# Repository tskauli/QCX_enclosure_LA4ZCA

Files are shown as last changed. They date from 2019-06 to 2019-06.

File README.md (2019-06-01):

# QCX_enclosure_LA4ZCA
A compact enclosure with integrated paddles for the QCX amateur radio transceiver kit

This note describes a design for a 3D printed enclosure for the QCX transceiver kit from QRP labs. The goal for the design has been to make a small and self-contained unit, to make it easy to bring the transceiver along for portable operation. Therefore, many features are built in:
•	paddles which can be flipped to a parking position for storage
•	speaker, in addition to an earphone connector
•	LiPo 4s battery, giving a transmit power of 5W
•	GPS for WSPR operation, enabled or disabled by the power switch

Construction is described in some detail in the document "Compact 3D printed QCX enclosure - construction notes"

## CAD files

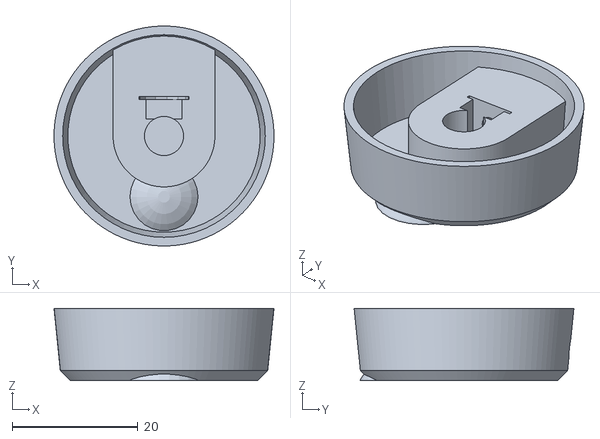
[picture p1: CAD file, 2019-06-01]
QCXtuning.stl
35.0 x 35.0 x 11.5

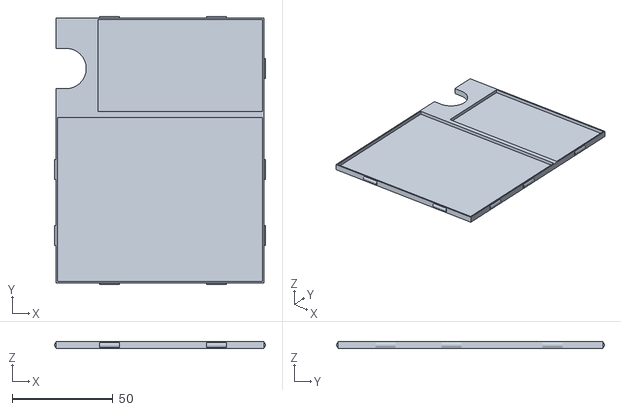
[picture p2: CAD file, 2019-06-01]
QCXcabinetLA4ZCAv30Lid.stl
104.5 x 132.7 x 3.50

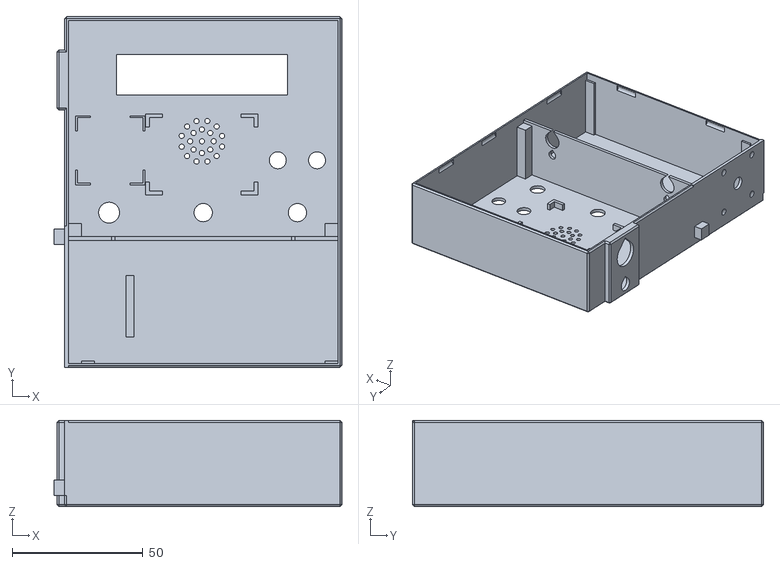
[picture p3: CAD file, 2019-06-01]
QCXcabinetLA4ZCAv30.stl
110.0 x 134.2 x 33.0

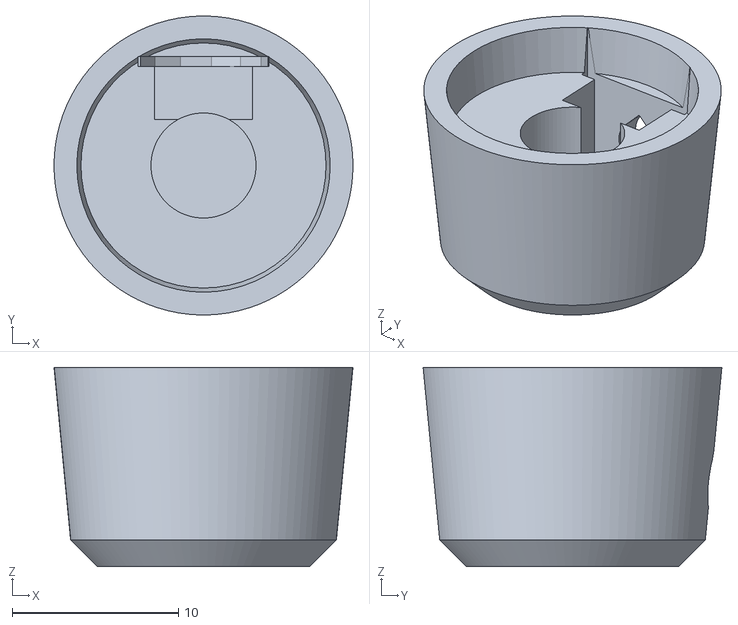
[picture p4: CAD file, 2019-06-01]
QCXvolume.stl
18.0 x 18.0 x 12.0

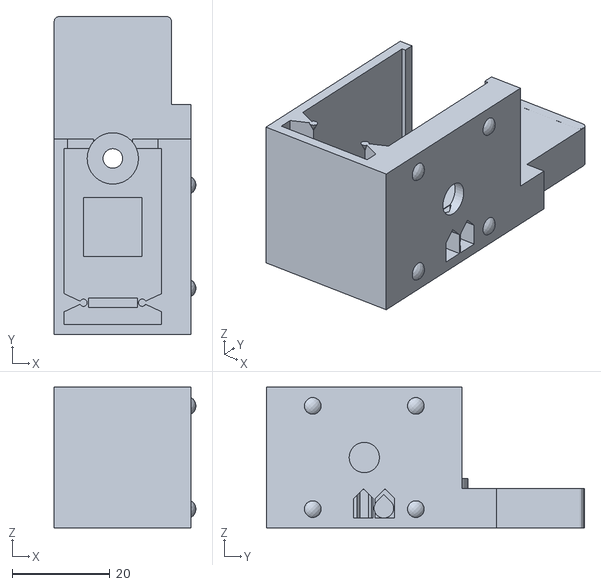
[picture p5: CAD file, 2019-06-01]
MorsePaddlesV2Base.stl
29.0 x 65.0 x 28.8

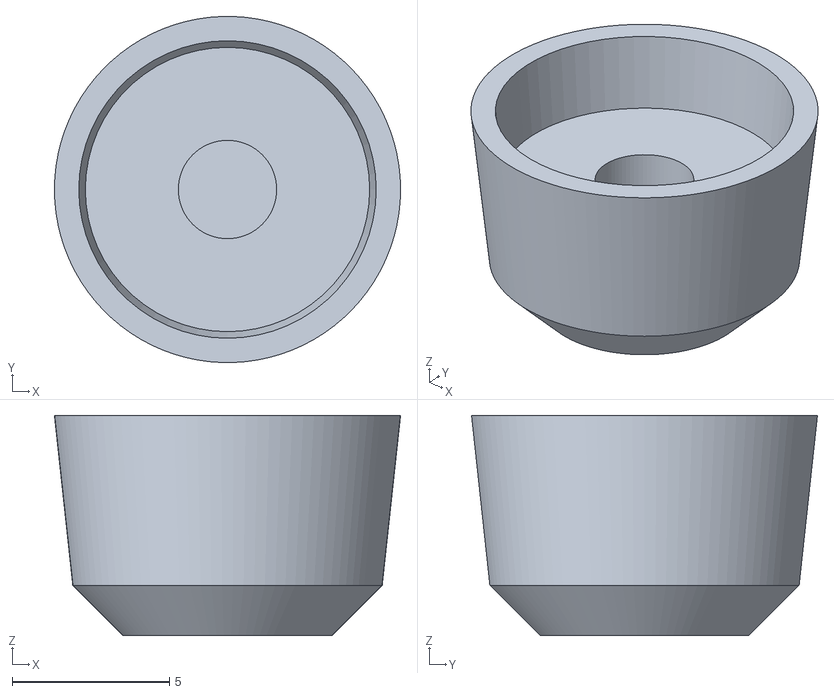
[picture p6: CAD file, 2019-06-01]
QCXpushbutton.stl
11.0 x 11.0 x 7.00

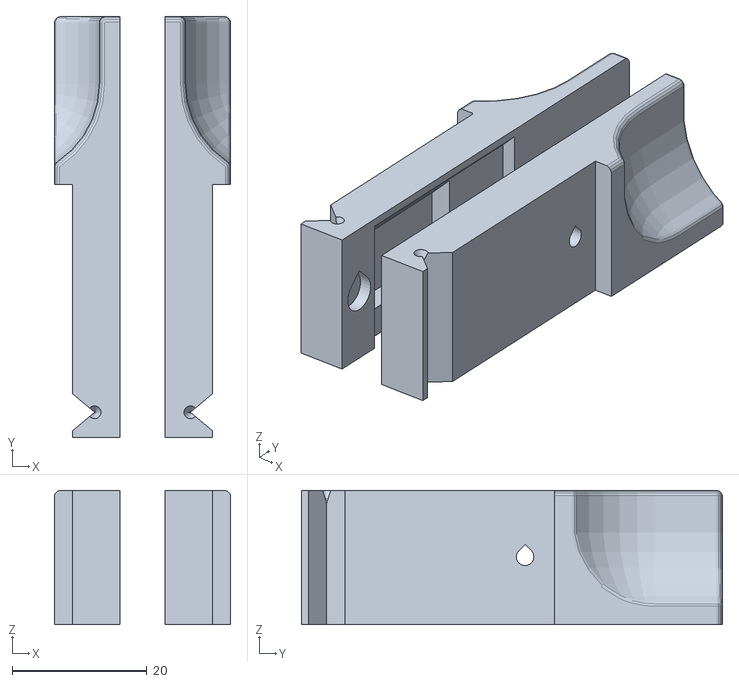
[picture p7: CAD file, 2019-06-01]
MorsePaddlesV2Arms.stl
26.2 x 62.6 x 20.0

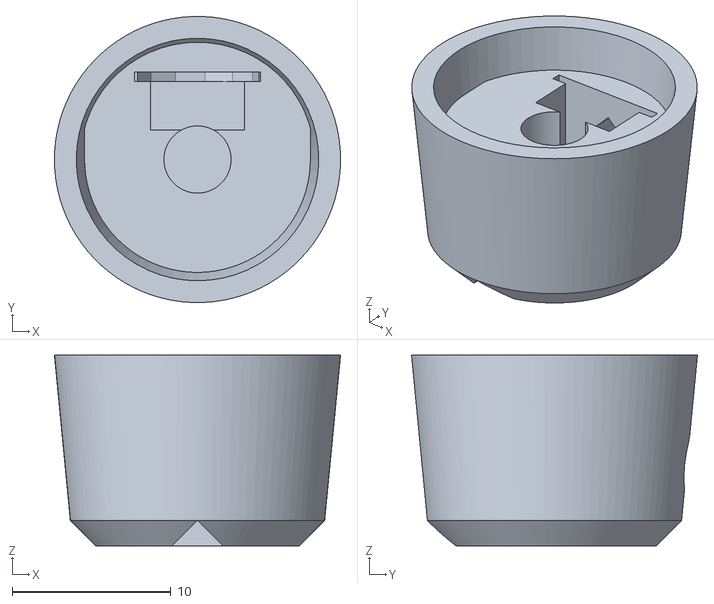
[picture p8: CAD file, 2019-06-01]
QCXpower.stl
18.0 x 18.0 x 12.0

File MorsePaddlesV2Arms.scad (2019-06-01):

/*

           >>> COMPACT 3D-PRINTED PADDLES <<<


    Torbjørn Skauli, LA4ZCA (tskauli@gmail.com)

                  v2.0, December 2018


Iambic paddles designed for 3D-printing. The design is simple, but provides precise movement with adjustable force and travel. Design features include a printed rocker hinge, force adjustment by a sliding spring, travel adjustment using a modified screw, ergonomic grip and general simplicity and precision.

Changes in v2.0: The paddles have been made narrower, and the base is thinner. There is an option to remove the bottom mounting holes. The base extends under the paddles to protect them from being pushed upwards. The cable exit is on the side, to fit mounting on the QCX transceiver.

TODO:
-Arms 1-2 mm higher, spring channel longer towards contacts?

Materials:
- 3 printed parts
- 2 screws M3x5mm, cylinder head, with washers for adjustment if needed
- 1 screw M4x25mm, cylinder head, with washer and nut
- Compression spring, 6-8 mm in diameter
- Compression spring, 4-5 mm in diameter
- Cable with plug as required, up to 3.5 mm diameter
Note: Dimensions of screws, springs and cable can be changed in the code.

Assembly:

- First, prepare the 3D-printed parts by removing support material in the arm spring well and in the ends of the cable holes. Also remove any protuding edges and bumps by gently filing the surfaces.

- Place the large spring so that it is held between the paddles approximately in the middle of the spring well. Also place the small spring in the holes at the hinge. Temporarily slide the two paddles in place. Check the spring force on the paddles and adjust as desired by either moving the spring along the well or by bending the spring to change its length. Make sure that the small spring keeps the arms in place at the hinges during use.

- Remove 6-8 cm of the outer isolation (if present) of the cable and 1 cm of the inner isolation of each wire. Insert the cable from the back through the diagonal hole, and temporarily pull it out from the side "window". Insert the cable back into the other hole and press the cable bend into the window so that the outer isolation ends in the interior wiring well. This forms a strain relief.

- Prepare a 25 mm (XXcheck) M4 screw with cylindrical head by grinding the outer 10 mm to flatten two opposing sides. Preferably align the flattened screw end with the slot in the screw head.

- Enter two M3 screws with cylindrical heads into the paddle arms, with the heads facing inwards. Clamp the dot and dash wire ends under these screw heads.

- Enter the M4 screw from the bottom and clamp the ground wire underneath the washer. Tighten the screw firmly, while allowing a small amount of adjustment of the screw angle to set the travel distance.

- Place the spring between the paddles and slide them in place. Adjust travel by rotating the M4 screw. If the travel is asymmetric, it may be necessary to correct the difference by placing a washer under the head of one of the M3 screws in the paddle arms.


*/

//*************** Rendering output control
mountholes=true;//Whether to have mounting holes in bottom
cacc=4;         // accuracy of circles, multiplier for $fn. Use cacc=1 for dev/debug, =2-4 for final.
preview=4;      // =0 for print layout,
                // =1 or =2 for 1- or 2-arm assembly preview,
                // =3 for base only
                // =4 for arms print layout,
                // =5 base+attachment preview
                // =6 base modified for attachment to other cabinet
                // =7 attachment for inclusion in other cabinet
                // =8 rotation stopper for inclusion in other cabinet

//**************** main parameters of the design
wxbase=24;      // overall width, sets arm thickness etc.
lybasemin=40;   // length excl. knobs (normally 40, made longer below for QCX)
hzarm=20;       // height of main part of arm
wallt=2;        // wall thikckness
wallmin=2;      // min wall thickness under cable holes

dfinger=30;     // approx diameter of finger for curved knob. Also knob length.
lyknob=25;                             // total length of knob
rround=1;       // radius of rounded edges on knob
txknobmin=2;    // min. thickness of knob

yhinge=6.5;     // y position of hinge relative to back
dxwedge=4;      // height of hinge wedge
ahinginn=50;    // angles for inner and outer part of hinges
ahingout=80;
dstopper=1.5;   // diameter of stopper on top of hinge that keeps arm down

armsep=0.75;     // arm separation from all walls
dyarmrests=2;   // y width of resting and bounding surfaces for arms
minstroke=0.25; // minimum stroke length (at full dia of center screw)

//**************** parameters for non-printed parts
dscrew1=4;      // screw dia, also scales screw head height
dscrew2=3;      // screw dia, also scales screw head height
hscrhrel=2/3;   // screw head height and diam rel to diameter
dscrhrel=7/4;
dzcontact=0.1;    // extra height of all screws
dzsprwell=-1;   // height adjustment of spring well
dcable=4;       // cable diameter
dspring=9.5;    // spring diameter
dhingespring=5; // diameter of spring keeping hinge in place

//*************** Parameters for cabinet attachment, needed to make integrated paddle
daxis=6;        // Diameter of rotation axis tube
lyflange=22;    // Length and height of flange on axis tube
hzflange=13;
atthick=1.5;
rotsnaph=1;     // Height of snaps for paddle attachment rotation
rotstop=7;      // Size of rotation stopper shelf

//**************** parameters for rendering
gap=0.2;        // gap for loose fit
tol=0.025;      // general tolerance
nil=0.001;     // Negligible distance, to correct rendering


lybase=lybasemin; // length of basee ex. knobs
echo("Length of base (mm):",lybase);
hzwall=hzarm+armsep;                        // total height of walls
hzbase=2*wallmin+dcable;                    // height of base under arms
ycontact=lybase-1*dscrew1;                  // position of contact screw

wxarm=wxbase/2-wallt-armsep-hscrhrel*dscrew2-minstroke-dscrew1/2; // arm thickness is the remaining space after removing many contributions to total width
echo("Total height (mm):",hzwall+hzbase);
echo("Total width for QCX (mm):",wxbase+dcable);
echo("Max length of contact screws in arms (mm):",wxarm);
echo("Min length of contact screw in base (mm):",hzbase-hscrhrel*dscrew1+armsep+hzarm/2+dscrew2*dscrhrel/2);
echo("Min length to flatten contact screw in base (mm):",dscrew2*dscrhrel);
wxknob=wxarm+wallt+armsep+hscrhrel*dscrew2;
dxknob=hscrhrel*dscrew2;                    // x offset toward center rel to main arm
hzknob=hzarm;                               // height of knobs
lyarm=lybase-wallt-armsep/2;                // knob spaced armsep/2 from base front

y0sprwell=yhinge-wallt-armsep+dxwedge*tan(ahingout/2);        // starting pos of spring channel
sprfloort=wallt;                            // thickness of floor underneath spring
sprlen=wxbase-2*(wallt+armsep+sprfloort);   // length of spring

dxtip=wxbase/4;                             // diameter of rounded tip with attachment hole
dytip=(wxbase-dxtip)/2;                     // length of tip ex rouned part
rtip=dxtip*sqrt(2)/2;                       // radius of tip
ycentip=lybase+dytip-rtip/sqrt(2);          // center of rounded tip
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

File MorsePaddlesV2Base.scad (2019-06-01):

/*

           >>> COMPACT 3D-PRINTED PADDLES <<<


    Torbjørn Skauli, LA4ZCA (tskauli@gmail.com)

                  v2.0, December 2018


Iambic paddles designed for 3D-printing. The design is simple, but provides precise movement with adjustable force and travel. Design features include a printed rocker hinge, force adjustment by a sliding spring, travel adjustment using a modified screw, ergonomic grip and general simplicity and precision.

Changes in v2.0: The paddles have been made narrower, and the base is thinner. There is an option to remove the bottom mounting holes. The base extends under the paddles to protect them from being pushed upwards. The cable exit is on the side, to fit mounting on the QCX transceiver.

TODO:
-Arms 1-2 mm higher, spring channel longer towards contacts?

Materials:
- 3 printed parts
- 2 screws M3x5mm, cylinder head, with washers for adjustment if needed
- 1 screw M4x25mm, cylinder head, with washer and nut
- Compression spring, 6-8 mm in diameter
- Compression spring, 4-5 mm in diameter
- Cable with plug as required, up to 3.5 mm diameter
Note: Dimensions of screws, springs and cable can be changed in the code.

Assembly:

- First, prepare the 3D-printed parts by removing support material in the arm spring well and in the ends of the cable holes. Also remove any protuding edges and bumps by gently filing the surfaces.

- Place the large spring so that it is held between the paddles approximately in the middle of the spring well. Also place the small spring in the holes at the hinge. Temporarily slide the two paddles in place. Check the spring force on the paddles and adjust as desired by either moving the spring along the well or by bending the spring to change its length. Make sure that the small spring keeps the arms in place at the hinges during use.

- Remove 6-8 cm of the outer isolation (if present) of the cable and 1 cm of the inner isolation of each wire. Insert the cable from the back through the diagonal hole, and temporarily pull it out from the side "window". Insert the cable back into the other hole and press the cable bend into the window so that the outer isolation ends in the interior wiring well. This forms a strain relief.

- Prepare a 25 mm (XXcheck) M4 screw with cylindrical head by grinding the outer 10 mm to flatten two opposing sides. Preferably align the flattened screw end with the slot in the screw head.

- Enter two M3 screws with cylindrical heads into the paddle arms, with the heads facing inwards. Clamp the dot and dash wire ends under these screw heads.

- Enter the M4 screw from the bottom and clamp the ground wire underneath the washer. Tighten the screw firmly, while allowing a small amount of adjustment of the screw angle to set the travel distance.

- Place the spring between the paddles and slide them in place. Adjust travel by rotating the M4 screw. If the travel is asymmetric, it may be necessary to correct the difference by placing a washer under the head of one of the M3 screws in the paddle arms.


*/

//*************** Rendering output control
mountholes=true;//Whether to have mounting holes in bottom
cacc=4;         // accuracy of circles, multiplier for $fn. Use cacc=1 for dev/debug, =2-4 for final.
preview=6;      // =0 for print layout,
                // =1 or =2 for 1- or 2-arm assembly preview,
                // =3 for base only
                // =4 for arms print layout,
                // =5 base+attachment preview
                // =6 base modified for attachment to other cabinet
                // =7 attachment for inclusion in other cabinet
                // =8 rotation stopper for inclusion in other cabinet

//**************** main parameters of the design
wxbase=24;      // overall width, sets arm thickness etc.
lybasemin=40;   // length excl. knobs (normally 40, made longer below for QCX)
hzarm=20;       // height of main part of arm
wallt=2;        // wall thikckness
wallmin=2;      // min wall thickness under cable holes

dfinger=30;     // approx diameter of finger for curved knob. Also knob length.
lyknob=25;                             // total length of knob
rround=1;       // radius of rounded edges on knob
txknobmin=2;    // min. thickness of knob

yhinge=6.5;     // y position of hinge relative to back
dxwedge=4;      // height of hinge wedge
ahinginn=50;    // angles for inner and outer part of hinges
ahingout=80;
dstopper=1.5;   // diameter of stopper on top of hinge that keeps arm down

armsep=0.75;     // arm separation from all walls
dyarmrests=2;   // y width of resting and bounding surfaces for arms
minstroke=0.25; // minimum stroke length (at full dia of center screw)

//**************** parameters for non-printed parts
dscrew1=4;      // screw dia, also scales screw head height
dscrew2=3;      // screw dia, also scales screw head height
hscrhrel=2/3;   // screw head height and diam rel to diameter
dscrhrel=7/4;
dzcontact=0.1;    // extra height of all screws
dzsprwell=-1;   // height adjustment of spring well
dcable=4;       // cable diameter
dspring=9.5;    // spring diameter
dhingespring=5; // diameter of spring keeping hinge in place

//*************** Parameters for cabinet attachment, needed to make integrated paddle
daxis=6;        // Diameter of rotation axis tube
lyflange=22;    // Length and height of flange on axis tube
hzflange=13;
atthick=1.5;
rotsnaph=1;     // Height of snaps for paddle attachment rotation
rotstop=7;      // Size of rotation stopper shelf

//**************** parameters for rendering
gap=0.2;        // gap for loose fit
tol=0.025;      // general tolerance
nil=0.001;     // Negligible distance, to correct rendering


lybase=lybasemin; // length of basee ex. knobs
echo("Length of base (mm):",lybase);
hzwall=hzarm+armsep;                        // total height of walls
hzbase=2*wallmin+dcable;                    // height of base under arms
ycontact=lybase-1*dscrew1;                  // position of contact screw

wxarm=wxbase/2-wallt-armsep-hscrhrel*dscrew2-minstroke-dscrew1/2; // arm thickness is the remaining space after removing many contributions to total width
echo("Total height (mm):",hzwall+hzbase);
echo("Total width for QCX (mm):",wxbase+dcable);
echo("Max length of contact screws in arms (mm):",wxarm);
echo("Min length of contact screw in base (mm):",hzbase-hscrhrel*dscrew1+armsep+hzarm/2+dscrew2*dscrhrel/2);
echo("Min length to flatten contact screw in base (mm):",dscrew2*dscrhrel);
wxknob=wxarm+wallt+armsep+hscrhrel*dscrew2;
dxknob=hscrhrel*dscrew2;                    // x offset toward center rel to main arm
hzknob=hzarm;                               // height of knobs
lyarm=lybase-wallt-armsep/2;                // knob spaced armsep/2 from base front

y0sprwell=yhinge-wallt-armsep+dxwedge*tan(ahingout/2);        // starting pos of spring channel
sprfloort=wallt;                            // thickness of floor underneath spring
sprlen=wxbase-2*(wallt+armsep+sprfloort);   // length of spring

dxtip=wxbase/4;                             // diameter of rounded tip with attachment hole
dytip=(wxbase-dxtip)/2;                     // length of tip ex rouned part
rtip=dxtip*sqrt(2)/2;                       // radius of tip
ycentip=lybase+dytip-rtip/sqrt(2);          // center of rounded tip
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

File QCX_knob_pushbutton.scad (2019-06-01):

/*

    **** ROBUST PARAMETRIC KNOB FOR ROTARY CONTROLS *****

    Torbjorn Skauli (tskauli@gmail.com)
    August 2018, released in the public domain.

This is a rotary knob such as those used for volume controls. The shape of the knob can be adjusted, mainly by changing its outer diameter, height and taper towards the top. It is also possible to add an arrow indicator on the top surface, and the shape can be made faceted rather than round. A bevelled edge around the top is also adjustable in the code.

The knob normally uses a set screw from the side. The screw is held by a nut resting on a washer, to ensure strength that allows for tightening. Either a headless setscrew can be used, or an optional recess for a flat head screw can be enabled. It is also possible to disable the screw and nut holes, for press fit on the shaft The inner structures can be recessed into the knob to enclose the mounting nut of the shaft in the panel.

The knob is designed to be printed upside down, and does not need any support material on printers capable of printing a 45-degree overhang, thanks to teardrop-shaped holes.

To assemble, first insert a washer and a nut in their slots, and then thread the screw in from the side. The washer may need to be pressed in with some force using pliers, depending on the accuracy of the print. If using a headed screw, the knob looks nicest if the screw length is such that the head is approximately flush with the outer surface when tightened.

*/
has_setscrew=0; // [ 1:include a set screw, 0:only shaft hole ]
has_arrow=0;    // [ 1:include an indicator arrow, 2:plain top ]
has_screwhead=0;// [ 1:screw with head - enlarged hole, 0:hex socket set screw ]

// No. of outer facets, or =0 if smooth
facets=0;       

// Pushbutton axis diameter
axdia=3.1; 

// Knob outer diameter
outdia=11;

// Height of outer part of knob
outheig=7;     

// Recess depth inside outer shell to accommodate pot panel mount nut
innerrecess=2.5;

// Radius reduction for tapering of main part, =0 for cylindrical shape.
rtaper=1*7/12;       

// set screw diameter
scrdia=3;       

/* [Hidden] */
twall=0.6;      // outer wall thickness
thinwall=0.5;   // thickness at the bottom of the axis hole (to push in as far as possible)
taxis=5;        // thickness of material around axis
tol=0.025;      // tolerance for fit, adapt to printer
gap=0.1;        // loose fit, adapt to printer
cacc=6;         // SPEED / ACCURACY scaling factor for $fn etc. 1=draft, >1=final
rbevel=1.6;     // delta radius to bevel start, also depth of arrow

// Hardware dimensions (adapted from. http://www.metrication.com/engineering/fastener.html)
scrhdia=2*scrdia;       // screw head diameter
washdia=2.6*scrdia;     // washer diameter and thickness
washthic=0.5+gap;       // washer thickness
nutdia=1.9*scrdia+gap;  // nut smallest diameter
nutdiaouter=2.2*scrdia; // nut largest diameter and thickness (check)
nutthic=0.9*scrdia+gap; // nut thickness
axgapfac=0.06;          // factor to move nut room closer to axis, rel to axis radius to avoid thin walls between nut and axis

wscrbase=axdia+2*taxis; // width of screw base
lscrbase=4*scrdia;      // length of screw base
innheig=outheig-innerrecess;// height of inner part
scrheig=innheig-max(washdia/2, scrdia);// height of screw hole

module teardropHole(lh,rh){ // Hole with 45-degree teardrop shape, no support material
    rotate([0,0,-135])
    union(){
        cylinder(h=lh,r1=rh,r2=rh,$fn=8*cacc);
        cube([rh,rh,lh]);
    };
};
module outershape(){ // Outer shape of knob
    union(){
        if (facets){
            translate([0,0,rbevel])
            cylinder(r1=(outdia)/2-rtaper,r2=outdia/2,h=outheig-rbevel,$fn=facets);
            cylinder(r1=(outdia)/2-rbevel-rtaper,r2=(outdia)/2-rtaper,h=rbevel,$fn=facets);
        }
        else{
            translate([0,0,rbevel])
            cylinder(r1=(outdia)/2-rtaper,r2=outdia/2,h=outheig-rbevel,$fn=15*cacc);
            cylinder(r1=(outdia)/2-rbevel-rtaper,r2=(outdia)/2-rtaper,h=rbevel,$fn=15*cacc);
        };
        
    };
};
module cavity(){ // inner cavity, to save plastic
    translate([0,0,max(twall,rbevel+thinwall)]) // cavity to save plastic
    cylinder(r1=(outdia)/2-twall-rtaper,r2=(outdia)/2-twall,h=outheig,$fn=10*cacc);
};
module axismount(){ // axis hole and clamp screw block
    intersection(){
        union(){ 
            // axis tube
            cylinder(d=axdia+2*taxis,h=innheig,$fn=15*cacc);
            // block for nut
            if (has_setscrew)
                translate([-wscrbase/2,0,0])
                cube([wscrbase,outdia/2,innheig]);
        };
        // ensure fit within outer shape
        outershape();
    };
};
module holes(){ // shapes to be carved out of the knob
    // axis hole
    translate([0,0,thinwall]) 
    cylinder(d=axdia+tol,h=innheig,$fn=12*cacc);

    // arrow indicator
    if (has_arrow)
        translate([0,-max(outdia/8,axdia/2+thinwall),0])
        rotate([90,0,0])
        cylinder(r=rbevel,h=outdia,$fn=4);
    
    // holes and recesses for screw, nut and washer
    if (has_setscrew) {
        // screw hole
        translate([0,0,scrheig])
        rotate([-90,0,0])
        teardropHole(rh=(scrdia+gap)/2,lh=outdia);
        
        //nut recess
        translate([-(nutdia+gap)/2,axdia*(0.5-axgapfac),scrheig-nutdiaouter/2-gap])
        cube([nutdia+gap,nutthic+axdia*axgapfac,outheig]);
        
        
        // washer recess, lower part
        translate([-(washdia+gap)/2,axdia/2+nutthic,scrheig-0*washdia/2-gap])
        cube([washdia+gap,washthic,outheig]);
        
        // washer recess, upper part
        translate([0,axdia/2+nutthic,scrheig])
        rotate([-90,0,0])
        #cylinder(d=washdia,h=washthic);

        // screw head recess
        if (has_screwhead)
            translate([0,axdia/2+nutthic+washthic+scrdia,scrheig])
            rotate([-90,0,0]) 
            teardropHole(rh=(scrhdia+gap)/2,lh=outdia);
    };
  
};
difference(){ // screw holes and arrow erosion
    union(){ // shell and screw mount
        difference(){
            outershape();
            cavity();
        };
        axismount();    

    };
        holes();
};

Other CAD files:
QCX_knob_tuning.scad
QCX_knob_volume-power.scad
QCXcabinetLA4ZCAv30.scad
QCXcabinetLA4ZCAv30Lid.scad
QCXcabinetPaddleAttach.scad

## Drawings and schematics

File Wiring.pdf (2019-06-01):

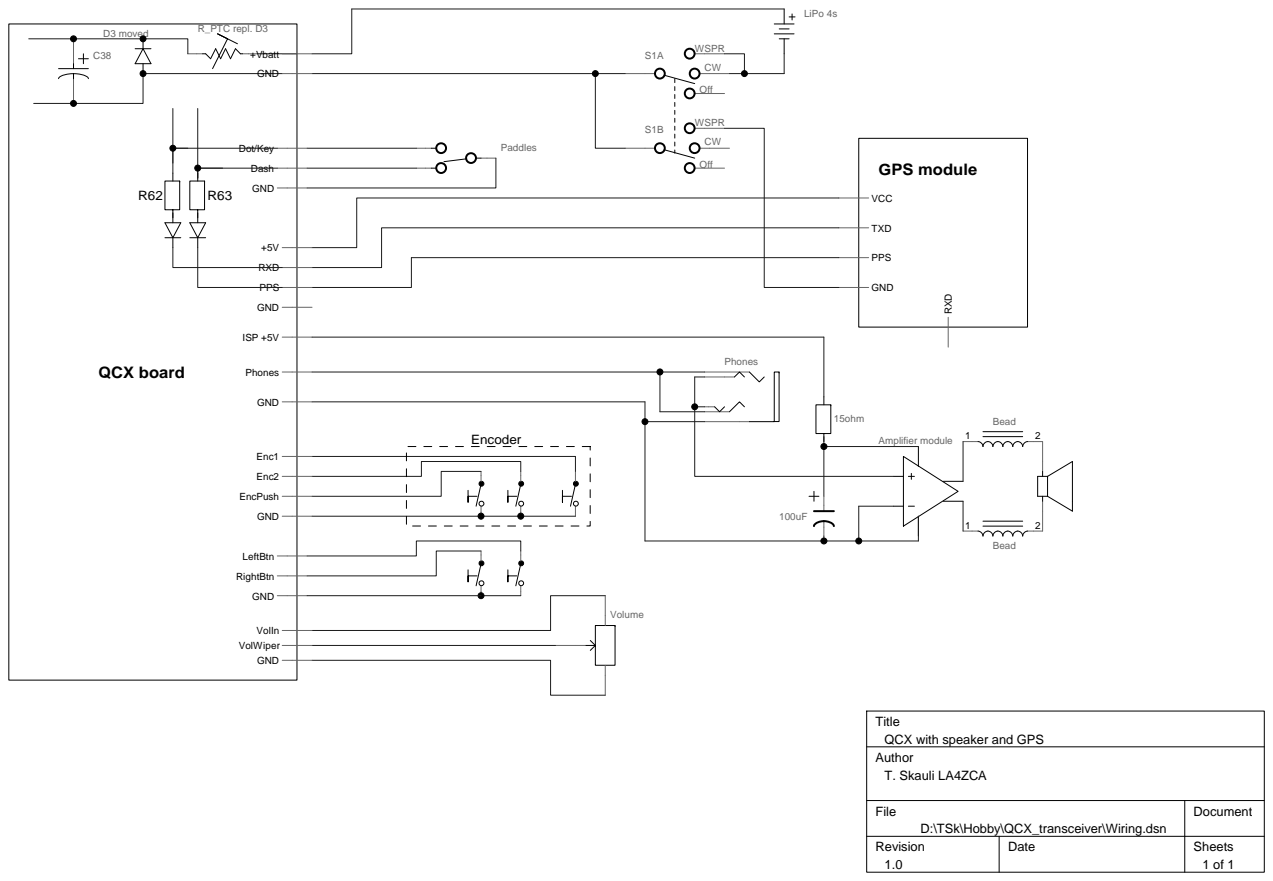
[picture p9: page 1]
WSPR; Off; LiPo 4s; Paddles; GPS module; TXD; VCC; PPS; GND; RXD; Amplifier module; Volume; Encoder; Phones; D3 moved; R_PTC repl. D3; QCX board; Enc1; Enc2; EncPush; LeftBtn; RightBtn; VolIn VolWiper GND; +Vbatt; Dot/Key; Dash; ISP +5V; 15ohm; Bead; File; Revision; Document; Date; Sheets

Title
QCX with speaker and GPS
Author
T. Skauli LA4ZCA

D:\TSk\Hobby\QCX_transceiver\Wiring.dsn

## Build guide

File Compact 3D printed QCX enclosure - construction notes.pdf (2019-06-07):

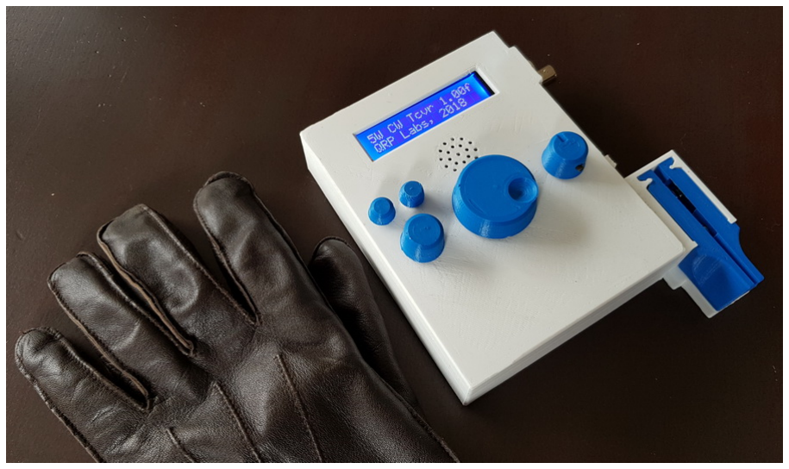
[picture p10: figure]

# A compact 3D printed enclosure for the QCX transceiver, with integrated paddles

Torbjorn Skauli, LA4ZCA (tskauli@gmail.com)

## Description

This note describes a design for a 3D printed enclosure for the QCX transceiver kit (https://www.qrp-labs.com/qcx.html) from QRP labs. (https://www.qrp-labs.com/) The goal for the design has been to make a small and self-contained unit, to make it easy to bring the transceiver along for portable operation. Therefore, many features are built in:
- paddles which can be flipped to a parking position for storage
- speaker, in addition to an earphone connector
- LiPo 4s battery, giving a transmit power of 5W
- GPS for WSPR operation, enabled or disabled by the power switch

If you want to reproduce the design from the provided documentation here, be warned that it is not entirely straightforward. There is a fair amount of wiring in addition to the 3D printing, and assembly is tight. You may have to adapt the 3D design to fit the parts available to you, or adjust the design according to the particulars of your 3D printer. For that, OpenSCAD source code is provided for the printed parts.

## Parts

OpenSCAD (https://www.openscad.org/) source and STL 3D files are provided for the enclosure, lid, paddles, and buttons. The enclosure imports parts via an intermediate include file QCXcabinetPaddleAttach.scad from a copy of the separate paddle design. Note that some of the provided source files are nearly identical, with different parameter settings to produce different parts. The other parts needed, in addition to the QCX kit itself, are:
- speaker amplifier module based on PAM8403
- Rotary switch, 2 pole 3 position (The build shown here uses a switch from Elma (https://www.elma.com/en/products/rotary-switches/rotary-switching-products/product-pages/type-01-detail/) for 8mm hole.)
- 2 momentary switches (The build shown here uses switches like these, (https://www.ckswitches.com/products/switches/product-details/Pushbutton/8020/) for 1/4 inch hole.)
- GPS module such as V.KEL VK2828U7G5LF
- 2 silicon diodes, 1N4148 or equivalent
- speaker, 28x40 mm
- earphone jack for hole mounting
- resistor 15 ohm
- electrolytic capacitor 100 uF, 6 volts
- ferrite beads, multi-hole
- optionally a 1A resettable polyfuse
- hardware for the paddles, as described in the text The parts are readily available from various online stores.

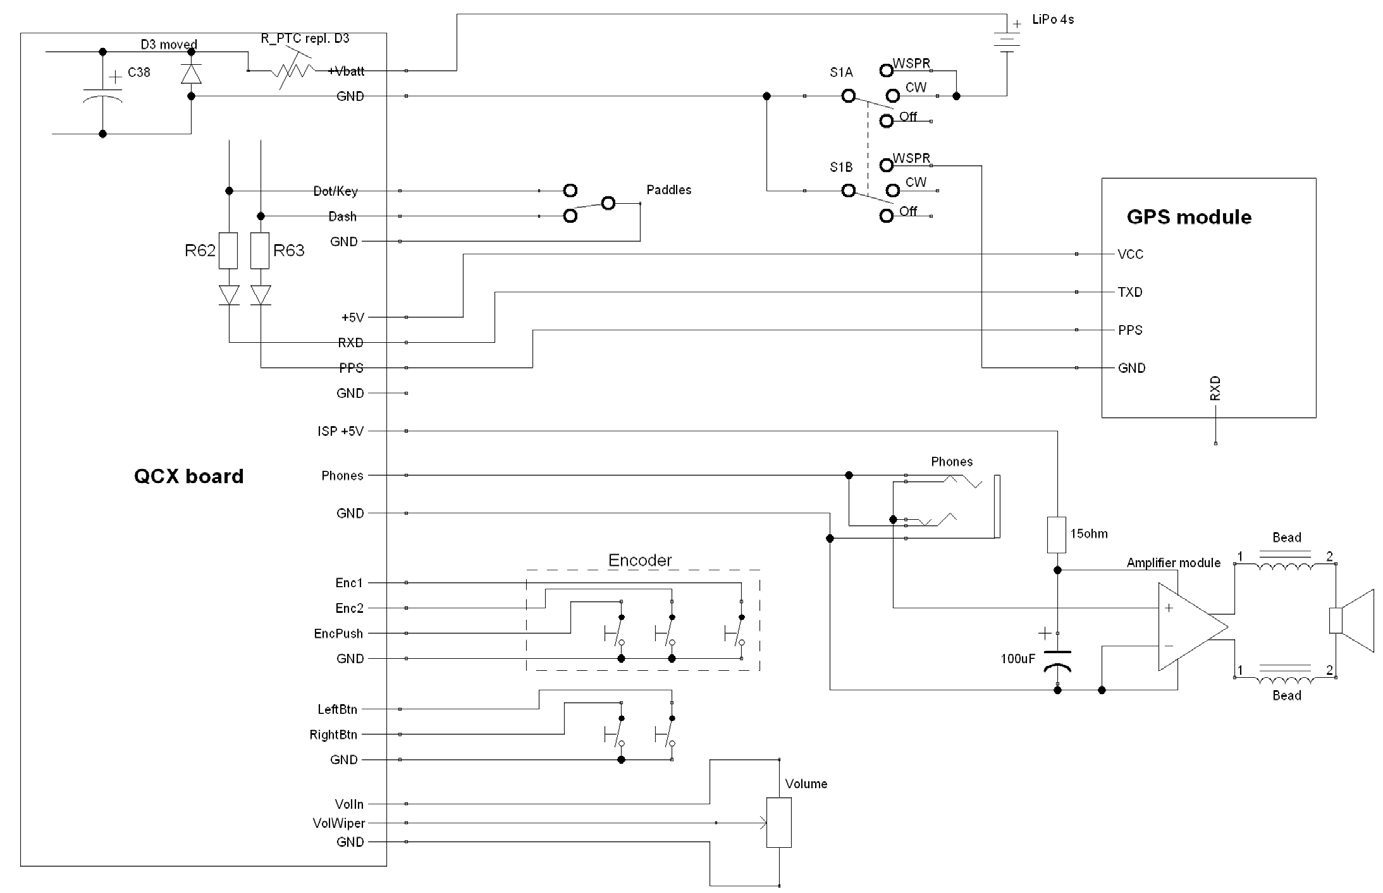
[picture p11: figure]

Figure 1. Wiring diagram. See text.

## Electrical

The wiring is shown in Figure 1. A 3-way 2-pole rotary switch connects power to the QCX, and also to the GPS when set in the WSPR position. The switch is in the ground lead so that when the GPS is off, it cannot pull the paddle lines low. Two diodes added in series with R62 and R63 ensure that the GPS is not affected by, or affecting, paddle signals when off.

A resettable polyfuse is mounted in the place of D3 to tame the potentially destructive current from the LiPo battery, also eliminating the diode voltage drop. For good measure, the diode is reused as a reverse polarity protection, by connecting it in the reverse direction across C38.

To make a GPS module work with the QCX, it turned out to be necessary to disable the "GLL" NMEA message. This requires the GPS module to be temporarily connected to a computer for reconfiguration, typically via a USB to serial adapter with TTL levels. I used the U-Blox U-Center (https://www.u-blox.com/en/product/u-center) software to do the reconfiguration. The V.KEL GPS unit turns out to be a favourable choice because it retains its settings indefinitely, while some other models depend on a small battery or supercap that eventually discharges, leading to a factory reset.

The speaker amplifier module used in my build is based on the PAM8403 class D amplifier (using only one of the stereo channels). The amplifier requires 5 volts, which is supplied from the unused ISP header, close to the regulator. There is an obvious risk of spurs and feedback from the amplifier. I was able to suppress such effects using the decoupling and filtering scheme shown, with an RC filter in the +5V supply and ferrite beads on the speaker wires. The beads are of a type with multiple holes, which turned out to give the best suppression. Getting the speaker audio to work properly at a decent volume may need some experimentation. Headphones can be connected via a jack, disconnecting the signal from the amplifier.

To make a bit more space above the main board, the QCX was slightly modified by adding extra 5 mm spacers underneath the LCD. This required a longer pin header to connect the LCD to the main board. Also, small aluminium heat spreaders were screwed to the 7805 regulator and glued to the PA transistors to make the QCX a bit more resilient to abuse. These details are shown in the pictures on the following pages. The remaining wiring is just standard off-board mounting of encoder, pushbutton switches and the volume control. On my unit I connected most wires using header connectors with 2.54 mm pin spacing, in order to reduce the risk of breakage of connections due to inevitable movements during assembly and testing.

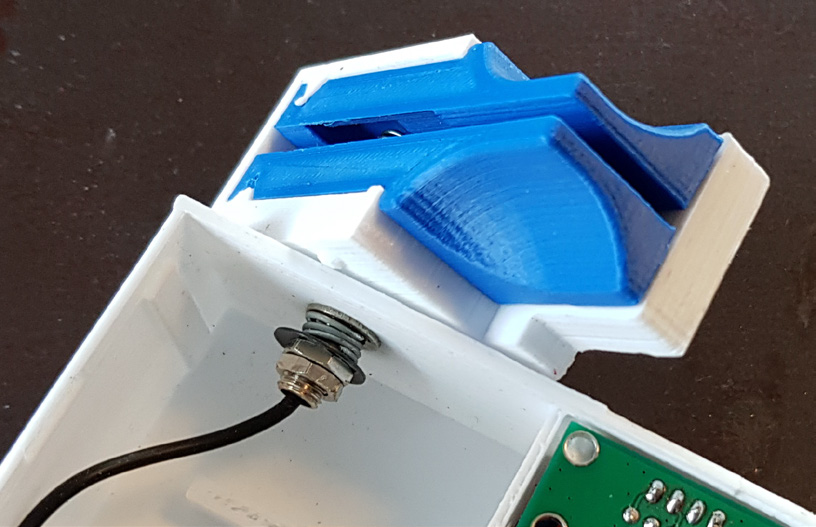
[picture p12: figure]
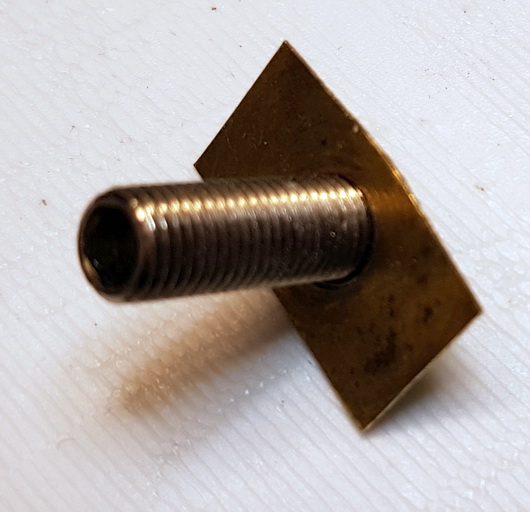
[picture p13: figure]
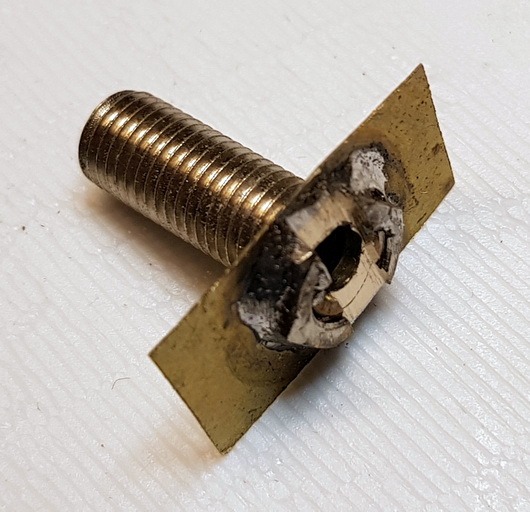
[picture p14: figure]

Figure 2. Left: Axis for paddle rotation. The flanged, threaded tube is fabricated from a banana jack and a piece of brass foil. Right: Spring loaded attachment of the paddle base to the QCX enclosure wall, with cable feedthrough. Note one of the bumps on the paddle wall for snapping the rotation movement in place in the operating or parked positions. See text.

## Mechanical

The most tricky part of the assembly is the paddle and its attachment to the QCX. The paddle design is described in a separate GitHub repository (https://github.com/tskauli/MorsePaddles) as well as on Thingiverse, (https://www.thingiverse.com/thing:3168497) but here are the particulars for the attachment to the enclosure: Start with the attachment of the paddle base to the cabinet wall. The rotation axis is shown in
Figure 2. This part is made from a banana jack with the back end cut off to form a threaded tube. A nut is entered on one end of the tube, and a small piece of brass foil is added to form a flange that fits inside the paddle base. These parts are soldered together as shown. To make more room for wires, file a slot in the nut afterwards. The tube is inserted from inside the paddle frame, with the flange resting against the inner wall. Now comes the tricky part of routing the wires. I used a thin, ultra-flexible cable from a pair of (worn-out) stereo earphones. Insert the cable through the tube into the paddle frame, then down and pull it from the opening at the bottom of the side wall. Then insert the end back into the horizontal hole to have a suitable (5-10 cm) length of wire coming out from the wiring well at the bottom of the paddle frame. Split the cable into three separate wires in a length of 3-5 cm. Remove isolation from the ends, which should be tinned, ready for clamping to the paddle contacts. Pull back any excess wire. Make sure that the wiring is flush with the outer wall, and out of the way of the paddle arms. Now insert the cable and tube into the cabinet wall and add a washer, a spring, another washer and a nut. Tighten the nut to get a firm spring loading of the paddle attachment. Then add a second nut as a jam nut to fix things in place. Now assemble the paddle arms according to the instructions for the paddle design.

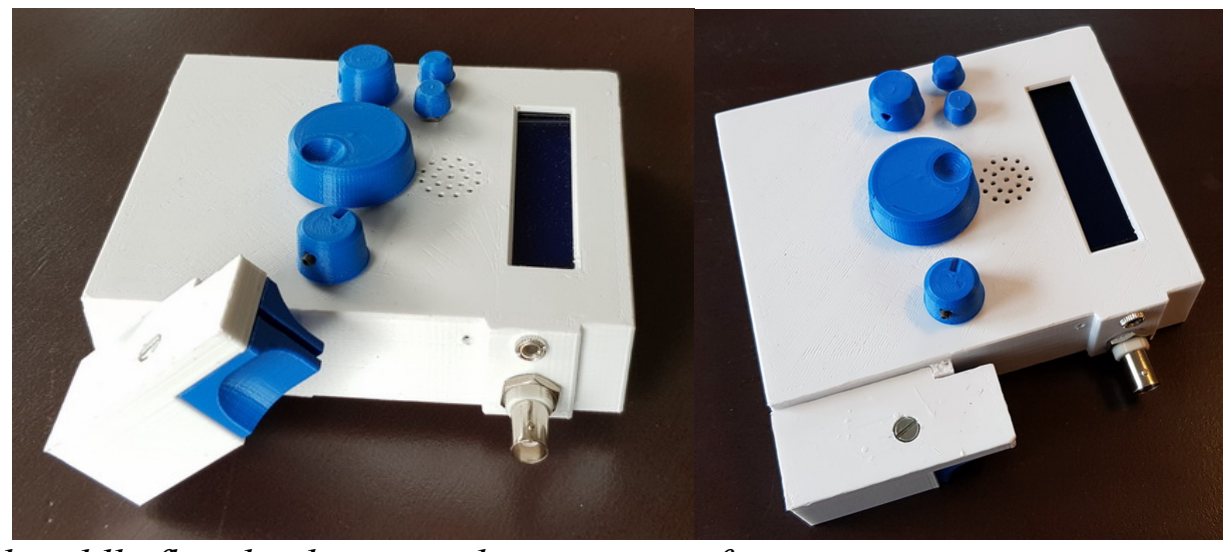
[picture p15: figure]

Figure 3. The finished paddle flips back to a parking position for easier storage.

The rest of the assembly is shown in the pictures on the following pages. Mount the controls and the earphone jack in their respective holes. The speaker and GPS module fit snugly in frames behind the front panel. Use a little glue, "Blue tack" putty, or tape to keep them in place. (Once all the wiring is in place, they will not have much room to move anyway.) Note that the LEDs on the GPS module are fairly visible through a white wall, but if a darker colour is used then you may want to make some small openings to be able to check the status of the PPS LED. The speaker amplifier module can be mounted with double-sided tape on the back of the volume pot. The remaining assembly consists of normal wiring of the hole-mounted controls to the QCX board. Wires to the battery and paddles can be routed through the slitted holes in the battery compartment wall. The design incorporates a small stopper in the battery compartment to keep the battery in place, which may need to be moved or removed depending on the choice of battery. Note that it is perfectly possible to change the size of the battery compartment by modifying parameters for battery size in the OpenScad code.

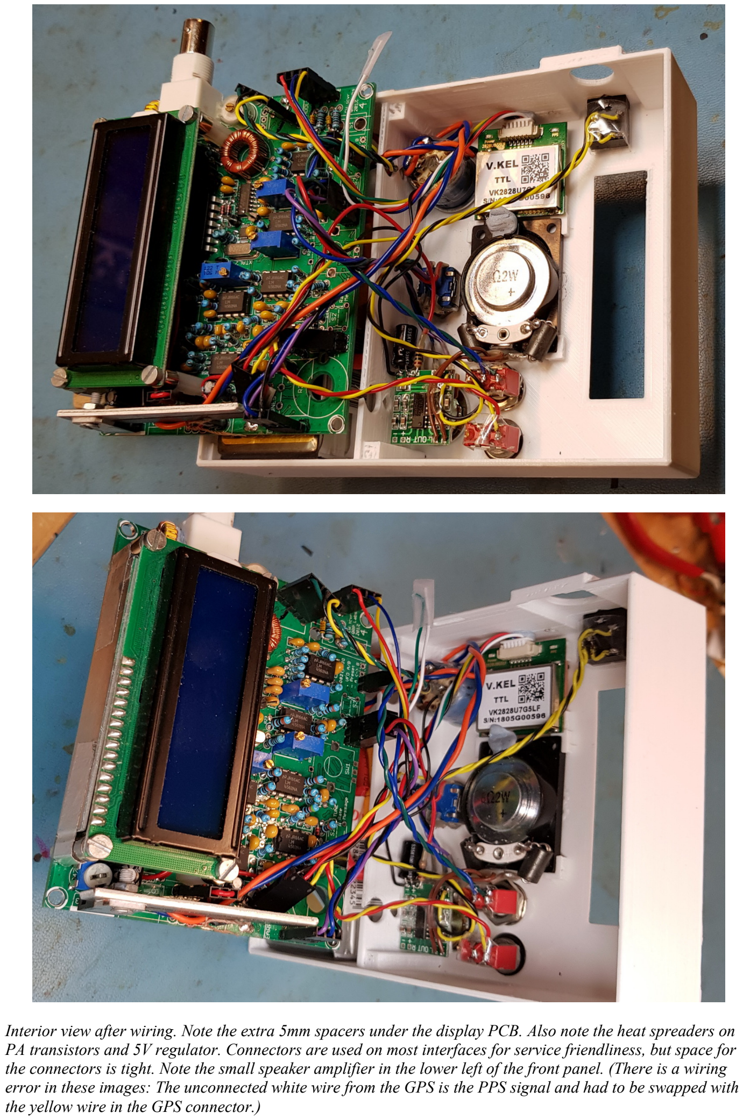
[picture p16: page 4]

Interior view after wiring. Note the extra 5mm spacers under the display PCB. Also note the heat spreaders on PA transistors and 5V regulator. Connectors are used on most interfaces for service friendliness, but space for the connectors is tight. Note the small speaker amplifier in the lower left of the front panel. (There is a wiring error in these images: The unconnected white wire from the GPS is the PPS signal and had to be swapped with the yellow wire in the GPS connector.)

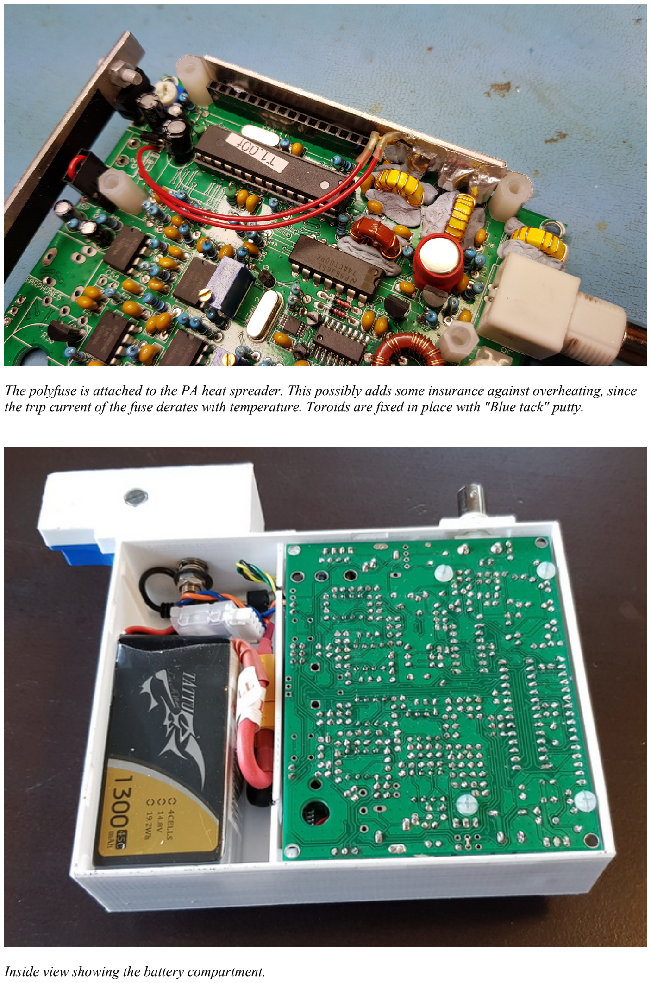
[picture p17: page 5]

The polyfuse is attached to the PA heat spreader. This possibly adds some insurance against overheating, since the trip current of the fuse derates with temperature. Toroids are fixed in place with "Blue tack" putty.

Inside view showing the battery compartment.

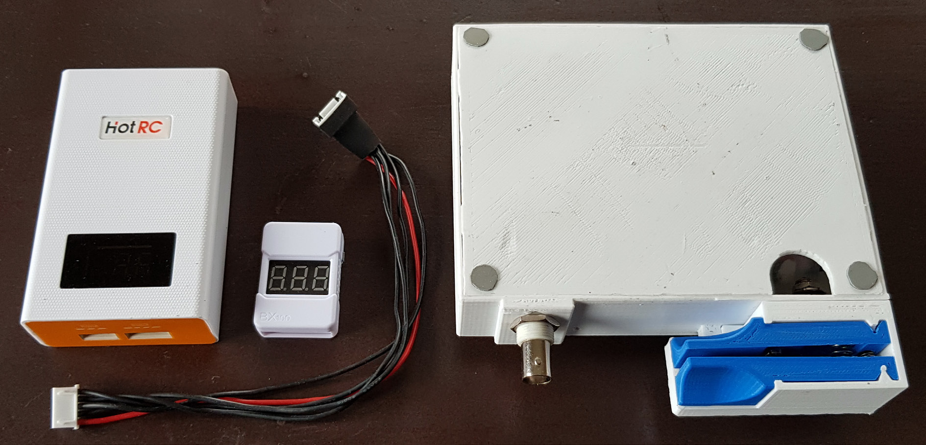
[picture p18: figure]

Bottom view showing the snap-on lid with a finger grip. Rubber pads help keep the unit in place during use. Also shown are some useful accessories: A balancing charger that connects to the balancing port of the battery, with extension cable, and a battery voltage indicator with audible low battery alarm. These items are readily available from various online stores. For long-time WSPR operation, the charger can be left connected while operating.

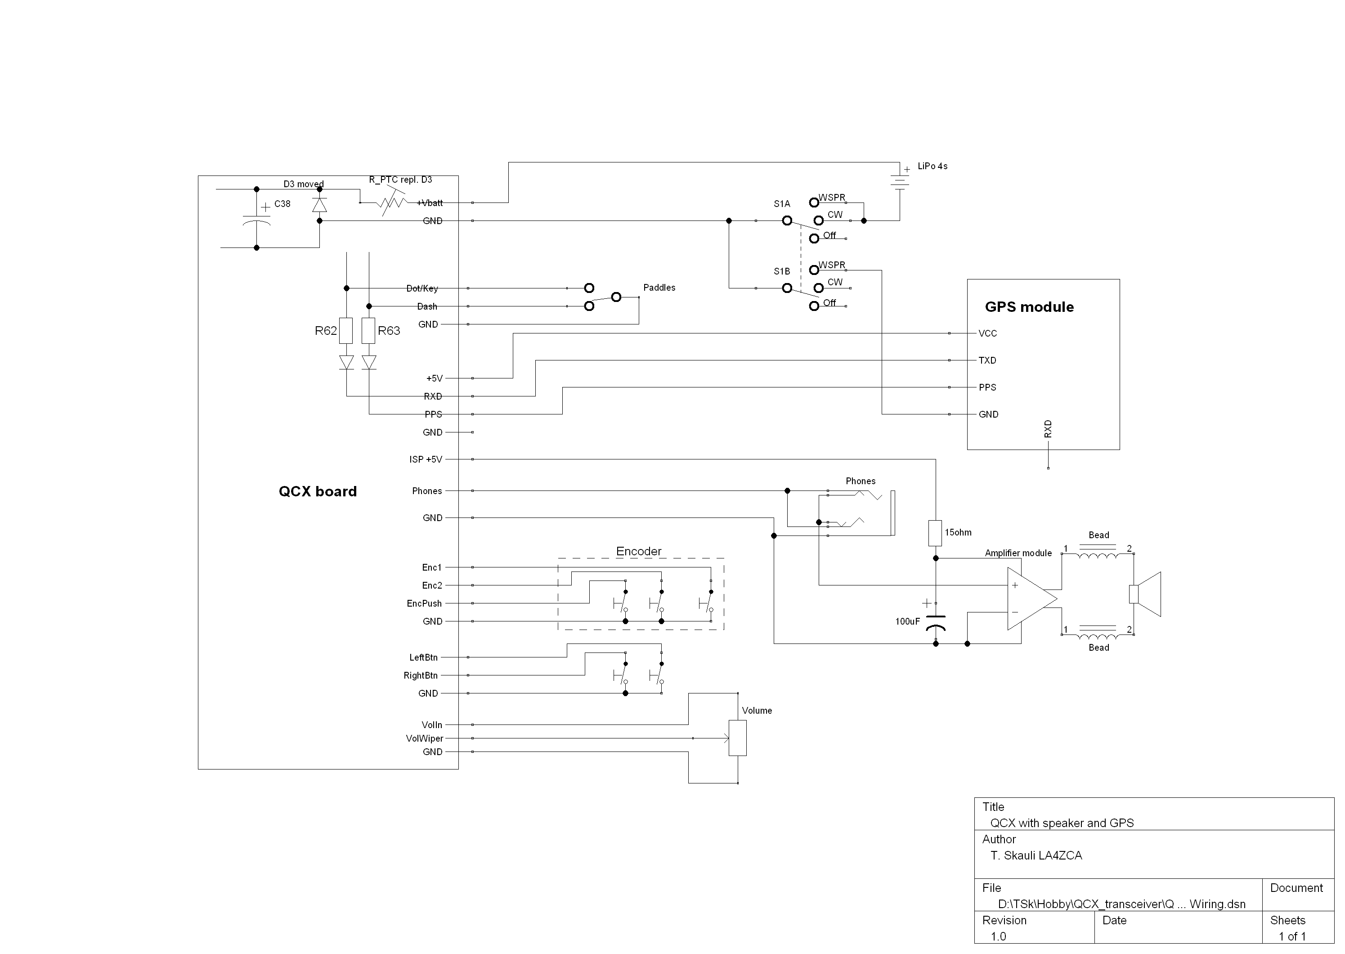
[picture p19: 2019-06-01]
Wiring.png
